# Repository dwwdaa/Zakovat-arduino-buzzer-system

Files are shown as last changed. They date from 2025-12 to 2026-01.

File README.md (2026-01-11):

# Arduino Quiz Buzzer System - Build Instructions

A DIY quiz buzzer system for games like **Svoyak** (Jeopardy-style) and **Brain Ring**. Supports up to 6 players/teams with countdown timer display and audio feedback.

---

## Parts List

### Electronics
| Component | Quantity | Notes |
|---|---|---|
| Arduino Mega 2560 R3 | 1 | Must be Mega (uses pins 22-37) |
| 1.8" 7-Segment Display (Common Cathode) | 2 | Single digit, 10-pin |
| Push Button | 6 | Any momentary switch |
| Active Buzzer | 1 | 5V, uses HIGH/LOW signal |
| 220Ω Resistor | 14 | One per display segment |
| Jumper Wires | ~40 | Male-to-male and male-to-female |
| USB Cable (Type-B) | 1 | For Arduino programming/power |

> [!WARNING]
> **Display Size & Power Consumption:**  
> Displays larger than 1.8" may require external power supply. Arduino Mega has a 200mA current limit via USB.
>
> **Current Calculation (with 220Ω resistors):**
> - LED forward voltage: ~2V
> - Supply voltage: 5V
> - Current per segment: (5V - 2V) / 220Ω = **~13.6mA**
> - Display 1 worst case (digit "8" + dot = 8 segments): 8 × 13.6mA = **~109mA**
> - Display 2 worst case (digit "8", no dot = 7 segments): 7 × 13.6mA = **~95mA**
> - Two displays worst case: 109 + 95 = **~204mA**
> - **Total estimated: ~204mA** (already exceeding 200mA limit)
>
> Larger displays have higher current draw per segment. If using bigger displays, consider:
> - Using higher value resistors (reduces brightness)
> - Powering displays from external 5V supply with common GND

### 3D Printed Parts
| File | Description | Quantity |
|---|---|---|
| `controller_case.stl` | Main Arduino enclosure | 1 |
| `controller_case_lid.stl` | Lid for controller | 1 |
| `display_case.stl` | Housing for displays | 1 |
| `display_case_lid.stl` | Lid for display housing | 1 |
| `display_stand.stl` | Stand for display case | 1 |
| `button_case_bottom.stl` | Player button base | 6 |
| `button_case_top.stl` | Player button top | 6 |

### Tools Needed
- Wire strippers / scissors
- 3D printer (or printing service)
- Zip ties (for cable management)
- Screwdriver

> [!TIP]
> Soldering is not required! Controller case has sockets to mount your wires using zip ties.

---

### Pin Reference Table

#### Buttons (use internal pullup - connect button between pin and GND)
| Button | Arduino Pin |
|---|---|
| Player 1 | D2 |
| Player 2 | D3 |
| Player 3 | D4 |
| Player 4 | D5 |
| Player 5 | D7 |
| Player 6 | D8 |

#### Buzzer
| Component | Arduino Pin |
|---|---|
| Buzzer (+) | D6 |
| Buzzer (-) | GND |

#### Display 1 (Seconds/Main digit) - via 220Ω resistors
| Segment | Arduino Pin |
|---|---|
| A | 22 |
| B | 23 |
| C | 24 |
| D | 25 |
| E | 26 |
| F | 27 |
| G | 28 |
| DP (dot) | 29 |
| Common Cathode | GND |

#### Display 2 (Tenths digit) - via 220Ω resistors
| Segment | Arduino Pin |
|---|---|
| A | 30 |
| B | 31 |
| C | 32 |
| D | 33 |
| E | 34 |
| F | 35 |
| G | 36 |
| DP (dot) | 37 |
| Common Cathode | GND |

---

## Assembly Steps

### Step 1: Prepare Wires
1. Gather jumper wires (male-to-male and male-to-female)
2. For buttons: prepare 2-wire cables (signal + GND) long enough to reach player positions
3. For displays: you'll need 9 wires per display (7 segments + dot + common cathode)

### Step 2: Prepare Resistors
1. Insert a 220Ω resistor inline with each segment wire (A-G and DP) for both displays
2. Use breadboard or twist resistor legs around wire ends, then cover with electrical tape
3. This limits current to ~13mA per segment, protecting the Arduino

> [!TIP]
> Alternatively, buy pre-made resistor jumper wires or use a small breadboard to connect resistors.

### Step 3: Wire the Displays
1. Connect Arduino pins 22-28 → resistors → Display 1 segments A-G
2. Connect Arduino pin 29 → Display 1 dot pin
3. Connect Arduino pins 30-36 → resistors → Display 2 segments A-G
4. Connect Arduino pin 37 → Display 2 dot pin
5. Connect both displays' common cathode pins to Arduino GND
6. Test with a simple sketch before continuing

### Step 4: Wire the Buttons
1. Connect one leg of each button to its designated Arduino pin
2. Connect the other leg to GND
3. The code uses internal pullup resistors, so no external resistors needed

### Step 5: Wire the Buzzer
1. Connect buzzer (+) to pin D6
2. Connect buzzer (-) to GND

### Step 6: Print & Assemble Cases
1. Print all STL files (recommended: PLA, 0.2mm layer height, 20% infill)
2. Install Arduino in `controller_case.stl`
3. Route wires through the case openings
4. Use zip ties in mounting sections to secure cables
5. Attach lid with `controller_case_lid.stl`
6. Mount displays in `display_case.stl`, add stand
7. Install buttons in `button_case_bottom.stl` + `button_case_top.stl`

### Step 7: Upload Code
1. Open Arduino IDE
2. Connect Arduino via USB
3. Open `svoyak.ino` or `brainring.ino`
4. Select **Board: Arduino Mega 2560** and correct COM port
5. Click Upload

---

## Usage

### Serial Commands
| Command | Action |
|---|---|
| `R` | Start new session (reset all) |
| `T` | Start countdown timer |
| `C` | Continue (Svoyak only) |

### Game Modes

**Svoyak (7-second timer):**
- Each player plays individually
- Press button to buzz in and stop timer
- Display shows player number + "P"

**Brain Ring (20-second timer):**
- Teams compete
- False start detection (shows player + "F")
- Pressing before timer starts = false start logged

### Display Indicators
- `X.P` = Player X pressed (valid)
- `X.F` = Player X false start
- `X.X` = Countdown timer (seconds.tenths)

---

## Troubleshooting

| Problem | Solution |
|---|---|
| Display shows nothing | Check common cathode is grounded, verify resistor connections |
| Segments are dim | Resistor value too high, try 180Ω |
| Button not detected | Check button wiring, ensure GND connection |
| Buzzer silent | Verify it's an active buzzer, check polarity |
| Wrong player number shown | Verify button pin assignments match code |

---

## Files Location
- **Arduino Code:** `Arduino/svoyak/` and `Arduino/brainring/`
- **3D Models:** `3ds Max 2026/export/`

---

## Images

### Real Game Usage

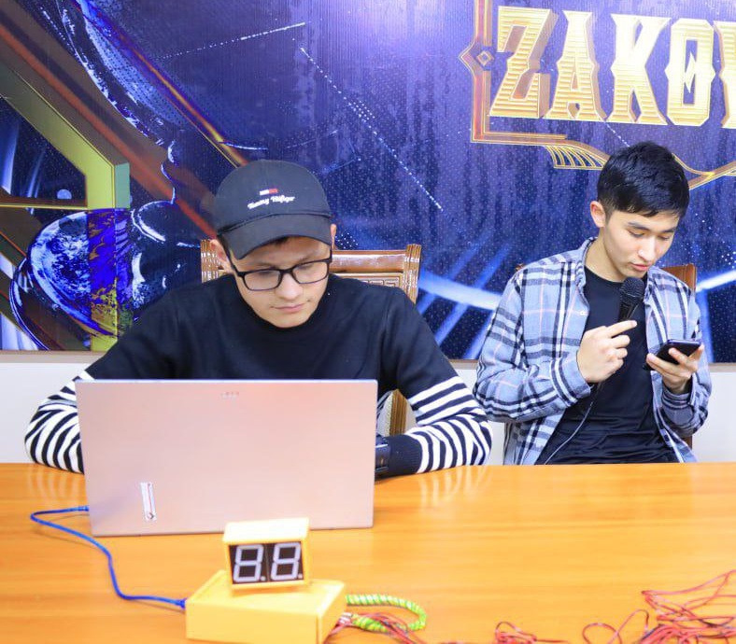
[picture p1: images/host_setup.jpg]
Host Setup


*Operator station with the controller unit and 7-segment display during a Zakovat game*

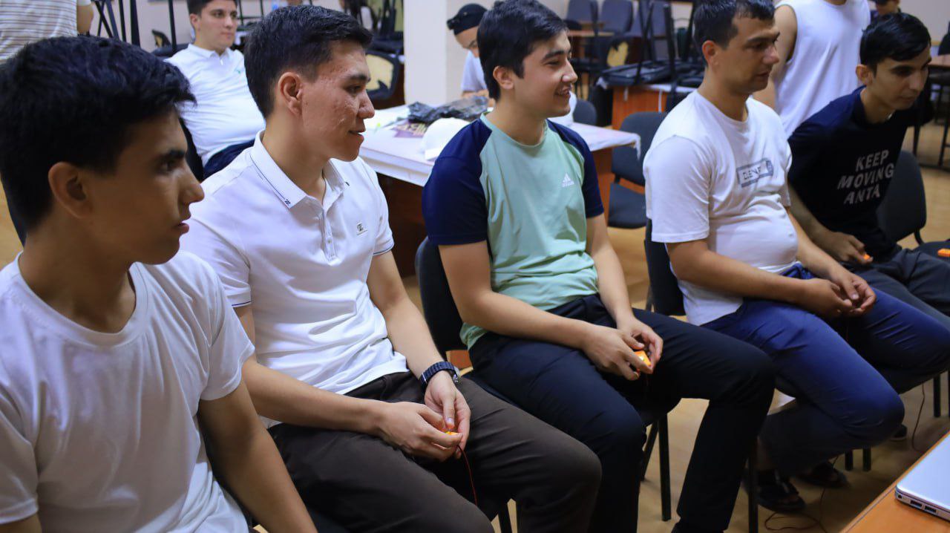
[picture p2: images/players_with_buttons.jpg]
Players with Buzzers

*Players holding the 3D printed buzzer buttons, ready to compete*

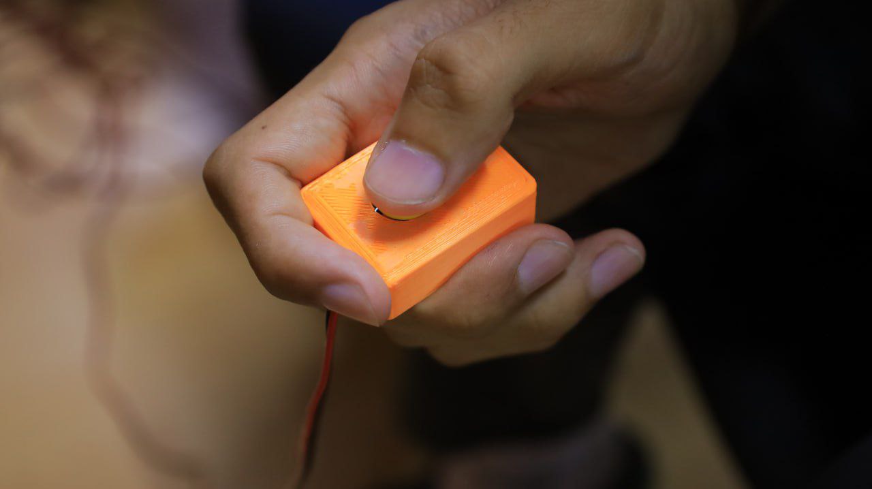
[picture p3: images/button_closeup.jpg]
Buzzer Close-up

*Close-up of the 3D printed buzzer button in hand*

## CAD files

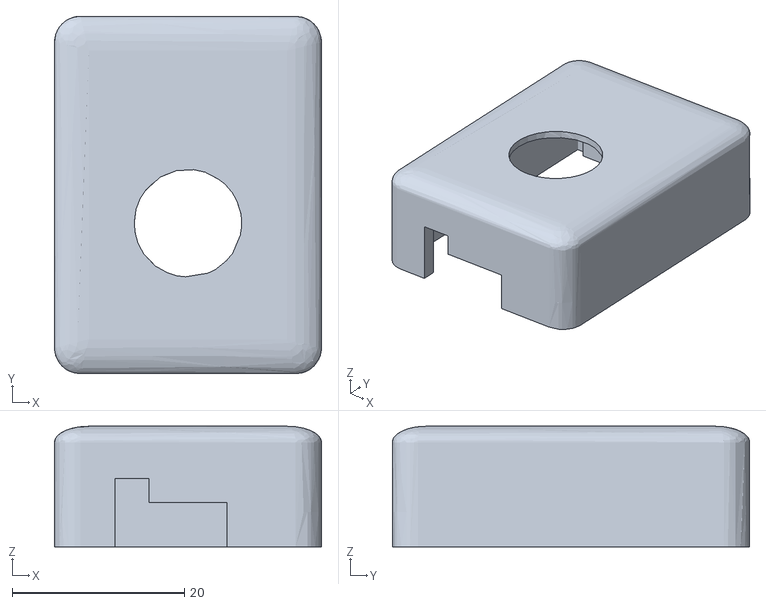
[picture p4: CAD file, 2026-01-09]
3D Printable casing/button_case_top.stl
31.0 x 41.5 x 14.0

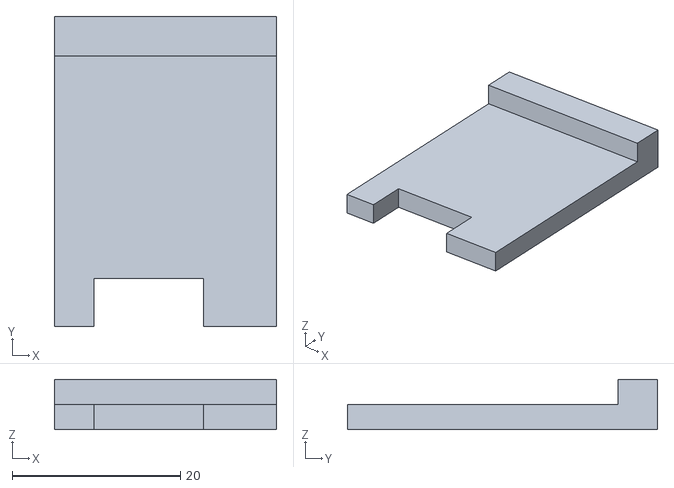
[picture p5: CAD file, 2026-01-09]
3D Printable casing/button_case_bottom.stl
26.4 x 36.9 x 6.00

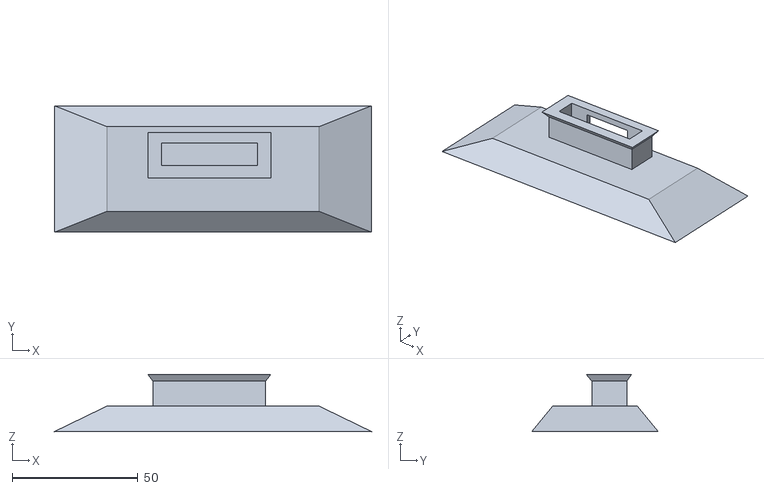
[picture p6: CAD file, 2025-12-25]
3D Printable casing/display_stand.stl
125.9 x 50.2 x 22.7

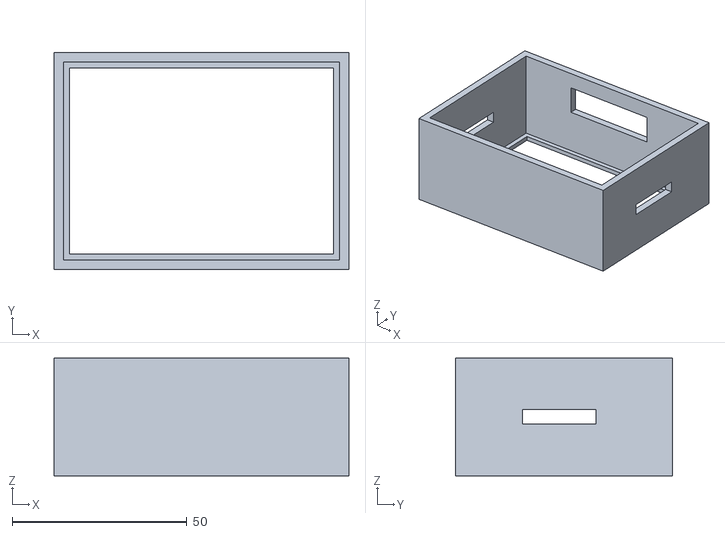
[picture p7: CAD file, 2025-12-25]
3D Printable casing/display_case.stl
84.3 x 62.0 x 33.7

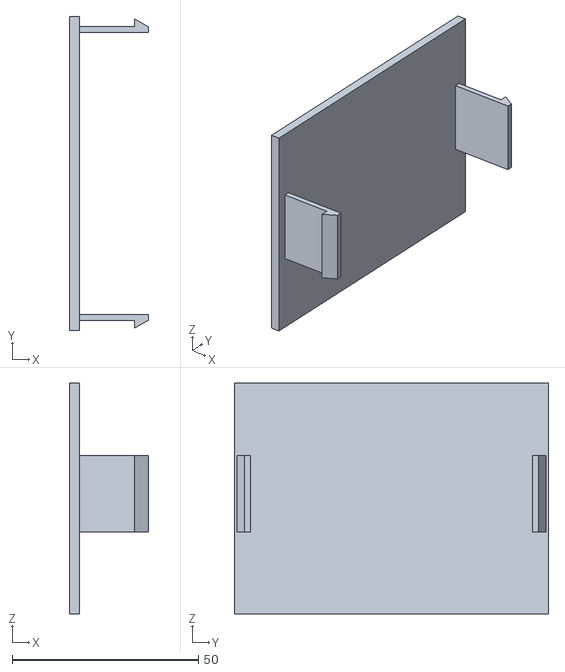
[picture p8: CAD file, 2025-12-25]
3D Printable casing/display_case_lid.stl
21.1 x 84.3 x 62.0

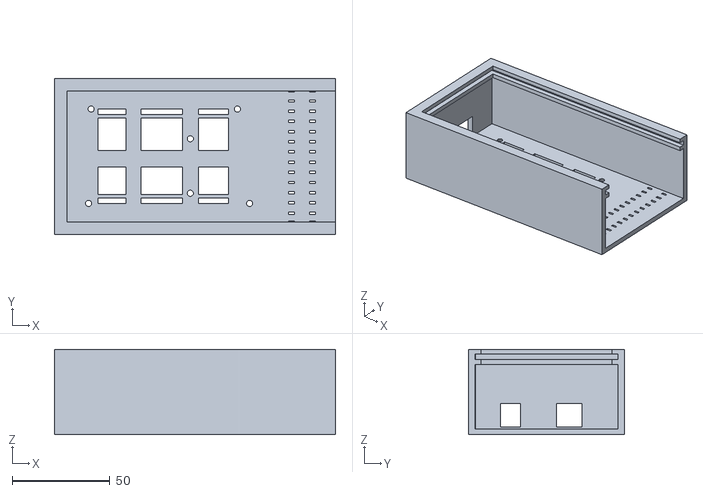
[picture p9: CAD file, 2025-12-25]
3D Printable casing/controller_case.stl
143.9 x 79.9 x 43.7

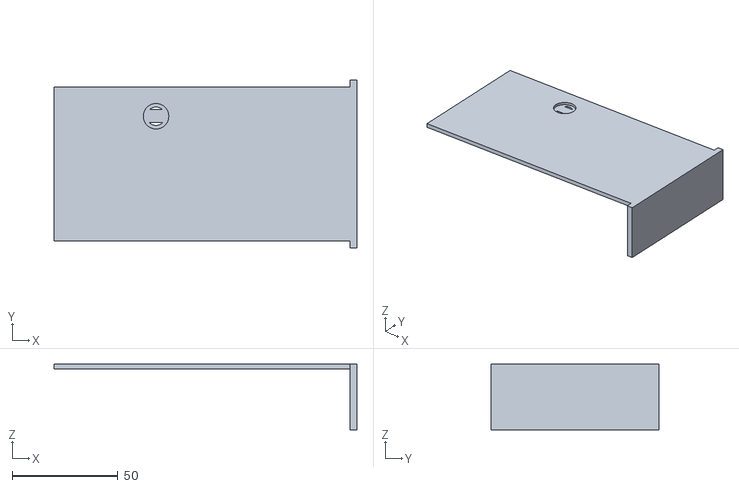
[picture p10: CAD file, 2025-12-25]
3D Printable casing/controller_case_lid.stl
143.5 x 79.7 x 31.1

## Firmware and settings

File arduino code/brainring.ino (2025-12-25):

const int buttonPins[6] = {2, 3, 4, 5, 7, 8};
const char* messages[6] = {"BUTTON_1", "BUTTON_2", "BUTTON_3", "BUTTON_4", "BUTTON_5", "BUTTON_6"};

const int buzzerPin = 6;

// 7-segment segment pins
int segmentPinsSeconds[7] = {22, 23, 24, 25, 26, 27, 28};
int segmentPinsTenths[7]  = {30, 31, 32, 33, 34, 35, 36};

int dotPinSeconds = 29;
int dotPinTenths  = 37;

const byte digits[10] = {
  B00111111, B00000110, B01011011, B01001111, B01100110,
  B01101101, B01111101, B00000111, B01111111, B01101111
};

const byte letterP = B01110011;

bool sessionActive = false;
bool timerRunning = false;
bool timerEnded = false;
bool buttonPressed = false;
bool continuelog = false;
int buttonIndexPressed = -1;

bool buttonUsed[6] = {false, false, false, false, false, false};

unsigned long sessionStart = 0;
unsigned long timerStart = 0;

// Track false starts
const int MAX_FALSE_STARTS = 6;
int falseStartIndices[MAX_FALSE_STARTS];
unsigned long falseStartTimes[MAX_FALSE_STARTS];
int falseStartCount = 0;

// Buzzer control variables
enum BeepType { NONE, ONCE, FALSE_START, LONG };
BeepType beepType = NONE;
int beepStep = 0;
unsigned long beepStartTime = 0;

// False start display tracking
int lastFalseStartButton = -1;
unsigned long lastFalseStartDisplayTime = 0;
bool showingFalseStart = false;

void setup() {
  Serial.begin(9600);
  for (int i = 0; i < 6; i++) pinMode(buttonPins[i], INPUT_PULLUP);
  pinMode(buzzerPin, OUTPUT);
  for (int i = 0; i < 7; i++) {
    pinMode(segmentPinsSeconds[i], OUTPUT);
    pinMode(segmentPinsTenths[i], OUTPUT);
  }
  pinMode(dotPinSeconds, OUTPUT);
  pinMode(dotPinTenths, OUTPUT);
  clearDisplays();
  Serial.println("Send 'r' to start session, 'T' to start timer.");
}

void displayDigit(int digit, int* segmentPins, bool dot = false) {
  if (digit < 0 || digit > 9) return;
  byte pattern = digits[digit];
  for (int i = 0; i < 7; i++)
    digitalWrite(segmentPins[i], pattern & (1 << i) ? HIGH : LOW);
  digitalWrite(segmentPins == segmentPinsSeconds ? dotPinSeconds : dotPinTenths, dot ? HIGH : LOW);
}

void loop() {
  updateBuzzer();

  // Auto-clear false start display after 2 seconds
  if (showingFalseStart) {
    if (millis() - lastFalseStartDisplayTime > 2000) {
      if (!timerRunning && !buttonPressed){
        clearDisplays();
      }
      showingFalseStart = false;
      lastFalseStartButton = -1;
    }
  }

  // Serial command handler
  if (Serial.available()) {
    char c = Serial.read();
    if (c == 'r' || c == 'R') {
      startSession();
    } else if ((c == 'T' || c == 't') && sessionActive && !timerRunning) {
      startTimer();
    }
  }

  // Button monitoring
  if (sessionActive) {
    for (int i = 0; i < 6; i++) {
      if (digitalRead(buttonPins[i]) == LOW && !buttonUsed[i]) {
        if (timerEnded) {
          continue;
        }
        buttonUsed[i] = true;
        unsigned long currentMillis = millis();
        float sinceSessionStart = (currentMillis - sessionStart) / 1000.0;

        if (!timerRunning && !continuelog && !timerEnded) {
          Serial.print(messages[i]);
          Serial.println(" false start");

          if (falseStartCount < MAX_FALSE_STARTS) {
            falseStartIndices[falseStartCount] = i;
            falseStartTimes[falseStartCount] = currentMillis;
            falseStartCount++;
          }

          beepFalseStart();

          // Update display to show false start
          lastFalseStartButton = i;
          lastFalseStartDisplayTime = millis();
          showingFalseStart = true;
          displayDigit(lastFalseStartButton + 1, segmentPinsSeconds, true);
          displayLetterF(segmentPinsTenths);
        } else {
          float elapsed = (currentMillis - timerStart) / 1000.0;
          Serial.print(messages[i]);
          Serial.print(" pressed at ");
          Serial.print(elapsed, 3);
          Serial.println(" seconds.");

          buttonIndexPressed = i;
          buttonPressed = true;
          timerRunning = false;
          timerEnded = true;
          if (!continuelog){
            displayDigit(buttonIndexPressed + 1, segmentPinsSeconds, true);
            displayLetterP(segmentPinsTenths);
            beepOnce();
          }
          continuelog = true;
        }
      }
    }
  }

  // Timer countdown
  if (timerRunning) {
    unsigned long elapsed = millis() - timerStart;
    float remaining = 20.0 - (elapsed / 1000.0);
    if (remaining < 0) remaining = 0;

    if (remaining >= 10.0) {
      displayDigit((int)remaining / 10, segmentPinsSeconds, false);
      displayDigit((int)remaining % 10, segmentPinsTenths, false);
    } else {
      displayDigit((int)remaining, segmentPinsSeconds, true);
      displayDigit(((int)(remaining * 10)) % 10, segmentPinsTenths, false);
    }

    if (elapsed >= 20000){ 
      endSession(false);
      continuelog = true;
    }
  }
}

// Buzzer logic
void beepOnce() {
  beepType = ONCE;
  beepStep = 0;
  beepStartTime = millis();
}
void beepFalseStart() {
  beepType = FALSE_START;
  beepStep = 0;
  beepStartTime = millis();
}
void beepLong() {
  beepType = LONG;
  beepStep = 0;
  beepStartTime = millis();
}
void updateBuzzer() {
  unsigned long now = millis();
  switch (beepType) {
    case ONCE:
      if (beepStep == 0) {
        digitalWrite(buzzerPin, HIGH);
        beepStep = 1;
        beepStartTime = now;
      } else if (beepStep == 1 && now - beepStartTime >= 300) {
        digitalWrite(buzzerPin, LOW);
        beepType = NONE;
      }
      break;
    case FALSE_START:
      if (beepStep == 0) {
        digitalWrite(buzzerPin, HIGH);
        beepStep = 1;
        beepStartTime = now;
      } else if (beepStep == 1 && now - beepStartTime >= 100) {
        digitalWrite(buzzerPin, LOW);
        beepStep = 2;
        beepStartTime = now;
      } else if (beepStep == 2 && now - beepStartTime >= 50) {
        digitalWrite(buzzerPin, HIGH);
        beepStep = 3;
        beepStartTime = now;
      } else if (beepStep == 3 && now - beepStartTime >= 100) {
        digitalWrite(buzzerPin, LOW);
        beepType = NONE;
      }
      break;
    case LONG:
      if (beepStep == 0) {
        digitalWrite(buzzerPin, HIGH);
        beepStep = 1;
        beepStartTime = now;
      } else if (beepStep == 1 && now - beepStartTime >= 700) {
        digitalWrite(buzzerPin, LOW);
        beepType = NONE;
      }
      break;
    case NONE:
      break;
  }
}

// Start session
void startSession() {
  sessionActive = true;
  timerRunning = false;
  timerEnded = false;
  buttonPressed = false;
  buttonIndexPressed = -1;
  continuelog = false;
  sessionStart = millis();
  falseStartCount = 0;
  showingFalseStart = false;
  lastFalseStartButton = -1;
  for (int i = 0; i < 6; i++) buttonUsed[i] = false;
  clearDisplays();
  Serial.println("Session started. Send 'T' to start timer.");
}

// Start timer
void startTimer() {
  timerStart = millis();
  beepOnce();
  timerRunning = true;
  timerEnded = false;
  continuelog = false;
  Serial.println("Timer started (20.0s countdown).");
  for (int i = 0; i < falseStartCount; i++) {
    float diff = (timerStart - falseStartTimes[i]) / 1000.0;
    Serial.print(messages[falseStartIndices[i]]);
    Serial.print(" has pressed button ");
    Serial.print(diff, 3);
    Serial.println(" seconds before timer.");
  }
  falseStartCount = 0;
}

// End session
void endSession(bool byButton) {
  timerRunning = false;
  timerEnded = true;
  if (byButton) {
    beepOnce();
  } else {
    beepLong();
    Serial.println("Timer ended.");
  }
}

void displayLetterP(int* segmentPins) {
  for (int i = 0; i < 7; i++) {
    digitalWrite(segmentPins[i], (letterP & (1 << i)) ? HIGH : LOW);
  }
}

void displayLetterF(int* segmentPins) {
  const byte letterF = B01110001;
  for (int i = 0; i < 7; i++) {
    digitalWrite(segmentPins[i], (letterF & (1 << i)) ? HIGH : LOW);
  }
}

void clearDisplays() {
  for (int i = 0; i < 7; i++) {
    digitalWrite(segmentPinsSeconds[i], LOW);
    digitalWrite(segmentPinsTenths[i], LOW);
  }
  clearDots();
}

void clearDots() {
  digitalWrite(dotPinSeconds, LOW);
  digitalWrite(dotPinTenths, LOW);
}

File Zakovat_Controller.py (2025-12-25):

import serial
import serial.tools.list_ports
import threading
import time
import os
from datetime import datetime
import sys
from pathlib import Path
import msvcrt

# ==== CONFIG ====
BAUD_RATE = 9600
BASE_DIR = Path(__file__).resolve().parent
LOG_DIR = BASE_DIR / 'logs'
os.makedirs(LOG_DIR, exist_ok=True)
LOG_PATH = os.path.join(LOG_DIR, f'serial_log_{datetime.now().strftime("%Y-%m-%d")}.txt')

# ==== AUTO DETECT ARDUINO COM ====
def find_arduino_port():
    ports = list(serial.tools.list_ports.comports())
    for p in ports:
        if "Arduino" in p.description or "CH340" in p.description or "USB-SERIAL" in p.description:
            return p.device  # e.g., 'COM5'
    return None

SERIAL_PORT = find_arduino_port()
if SERIAL_PORT is None:
    print("⚠️  Arduino not found. Make sure it's connected.")
    sys.exit(1)

# ==== SERIAL SETUP ====
try:
    ser = serial.Serial(SERIAL_PORT, BAUD_RATE, timeout=0.1)
except Exception as e:
    print(f"[ERROR] Failed to open {SERIAL_PORT}: {e}")
    sys.exit(1)

# ==== LOGGING ====
def log_line(prefix, msg):
    timestamp = datetime.now().strftime("[%Y-%m-%d %H:%M:%S]")
    with open(LOG_PATH, 'a') as f:
        f.write(f"{timestamp} {prefix} {msg}\n")

# ==== SERIAL READER THREAD ====
def read_serial():
    while True:
        try:
            if ser.in_waiting:
                line = ser.readline().decode(errors='ignore').strip()
                if line:
                    print(f"<< {line}")
                    log_line("<<", line)
        except Exception as e:
            print(f"[ERROR reading serial]: {e}")
            break

# ==== GET KEY FUNCTION ====
def get_char(timeout=0.1):
    if msvcrt.kbhit():
        return msvcrt.getwch()
    return None

# ==== SENDER ====
def send_message(msg):
    if ser and ser.is_open:
        ser.write((msg + '\n').encode())
        print(f">> {msg}")
        log_line(">>", msg)

# ==== MAIN LOOP ====
def main():
    print(f"✅ Connected to {SERIAL_PORT}")
    print("Type messages and press Enter to send.")
    print("Press R, T, or C keys directly to send those (case-insensitive).")
    print("Press Ctrl+C to exit.\n")

    # Start serial reading thread
    threading.Thread(target=read_serial, daemon=True).start()

    buffer = ""
    try:
        while True:
            ch = get_char()
            if ch:
                if ch in ['\r', '\n']:
                    if buffer.strip():
                        send_message(buffer.strip())
                    buffer = ""
                    print("> ", end='', flush=True)
                elif ch.lower() in ['r', 't', 'c'] and len(buffer.strip()) == 0:
                    send_message(ch.upper())
                elif ord(ch) == 3:  # Ctrl+C
                    break
                elif ord(ch) == 127:  # Backspace
                    buffer = buffer[:-1]
                    sys.stdout.write("\b \b")
                    sys.stdout.flush()
                else:
                    buffer += ch
                    print(ch, end='', flush=True)
    except KeyboardInterrupt:
        print("\nExiting...")

    finally:
        if ser and ser.is_open:
            ser.close()

if __name__ == "__main__":
    main()

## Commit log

2025-12-25 Add solo mode functionality to Arduino code
    This file contains the implementation of a solo mode for an Arduino project, including button handling, timer functionality, and buzzer control.
    [solo_mode.ino]
2026-01-09 Create 3D Printable casing
2026-01-11 Add build instructions for Arduino Quiz Buzzer System
    Added detailed build instructions for the Arduino Quiz Buzzer System, including parts list, assembly steps, usage, troubleshooting, and images.
2026-01-11 Fix Arduino Mega current limit in README
    Updated current limit for Arduino Mega in warnings.
